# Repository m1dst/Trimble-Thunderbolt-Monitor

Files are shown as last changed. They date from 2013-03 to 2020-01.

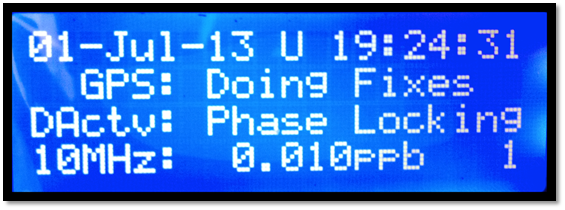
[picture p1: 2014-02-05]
Example-LCD.png

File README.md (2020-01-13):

**ATTENTION: We now support TinyCLR and as such the cheap GHI Fez which only costs $10**

If you are reading this for the first time and have not purchased a microcontroller yet, I suggest you use TinyCLR and the GHI Fez as the other boards are becomming more expensive and use the older NETMF.  Many suppliers have this board and an example supplier is [Mouser](https://www.mouser.co.uk/ProductDetail/GHI-Electronics/FEZT18-N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).  This will be the easiest way for you to run this project although the documentation I provide has yet to be updated so you will need to check out the ["getting started" guide](https://docs.ghielectronics.com/software/tinyclr/getting-started.html) on how to setup the environment for flashing the board.

**If you don't know how to use GitHub and just want to download the latest development code, visit [https://github.com/m1dst/Trimble-Thunderbolt-Monitor/archive/master.zip](https://github.com/m1dst/Trimble-Thunderbolt-Monitor/archive/master.zip).  You can always redownload the latest version with this link.  If you want an official releases, click the [releases link](https://github.com/m1dst/Trimble-Thunderbolt-Monitor/releases).**

Thunderbolt Monitor is a stand-alone microprocessor-controlled LCD specifically for the [Trimble Thunderbolt](http://www.trimble.com/timing/thunderbolt-e.aspx) disciplined clock, providing a comprehensive indication of the Thunderbolt's status, modes, and alarm conditions written in C# (NETMF).

Data packets appearing on Thunderbolt's serial port are in Trimble Standard Interface Protocol (TSIP), not NMEA sentences, so this display will not work with NMEA GPS units, such as Trimble's Jupiter or any other GPS.

Ideal for amateur radio applications, Thunderbolt Display shows Time Of Day (UTC) to assist with logging contacts, and also calculates Maidenhead Grid Locator Square from the current latitude and longitude.

The software runs on a [Netduino](https://www.wildernesslabs.co/) or [GHI FEZ Lemur](http://ghielectronics.com/) which is a .NET version of the popular Arduino platform.  It also requires a shield to make connecting it up to the microcontroller much cleaner.  I have designed the shield to be compatible with both Netduino and Arduino in case *someone wants to write code for the other platform.*

There are **four** projects in this repo.

* TrimbleMonitor (TinyCLR - Fez) – Basic monitor for the GHI FEZ (No NTP)
* TrimbleMonitor (Fez Lemur) – Basic monitor for the GHI FEZ Lemur (No NTP)
* TrimbleMonitor (Netduino) – Basic monitor for any Netduino 1, 2, 3 (No NTP)
* TrimbleMonitor (Netduno Plus) – Monitor with NTP support for a Netduino 2+ / 3 Ethernet / 3 WiFi

**The board must be running TinyCLR or [.NET Micro Framework 4.3](http://netmf.codeplex.com/releases/view/611040).  You should use [Visual Studio 2013](http://download.microsoft.com/download/2/5/5/255DCCB6-F364-4ED8-9758-EF0734CA86B8/wdexpress_full.exe) for NETMF projects and Visual Studio 2019 for TinyCLR.  More information can be found within the instructions document.**

Blog posts can be found at http://www.m1dst.co.uk/category/projects/trimble-thunderbolt-monitor/

Contains an NTP server implementation which allows you to sync your computer clock with the Trimble Thunderbolt.

You can now buy the shield as a PCB from [http://www.m1dst.co.uk/shop/](http://www.m1dst.co.uk/shop/)

The Netduino and GHI FEZ Lemur and GHI Fez are available from a few places but consistently seem to be in stock at Mouser.

**I do not have a version of the code for Arduino but I'm happy to include it in this repo if you wanted to write it.  The board I recommend now is the $10 GHI Fez running TinyCLR.  I have yet to update the instructions for flashing this but there are plenty of guides on the GHI website. **

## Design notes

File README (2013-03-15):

This is a hardware and software project to monitor and command a Trimble Thunderbolt which is a GPS disciplined 10MHz reference.

The software runs on a Netduino which is a .net version of the popular Arduino platform.  It also includes a shield to make connecting it up to the Netduino much cleaner.  I have designed the shield to be compatible with both Netduino are Arduino in case someone wants to port to the other platform.

Blog posts can be found at http://www.m1dst.co.uk/category/projects/trimble-thunderbolt-monitor/

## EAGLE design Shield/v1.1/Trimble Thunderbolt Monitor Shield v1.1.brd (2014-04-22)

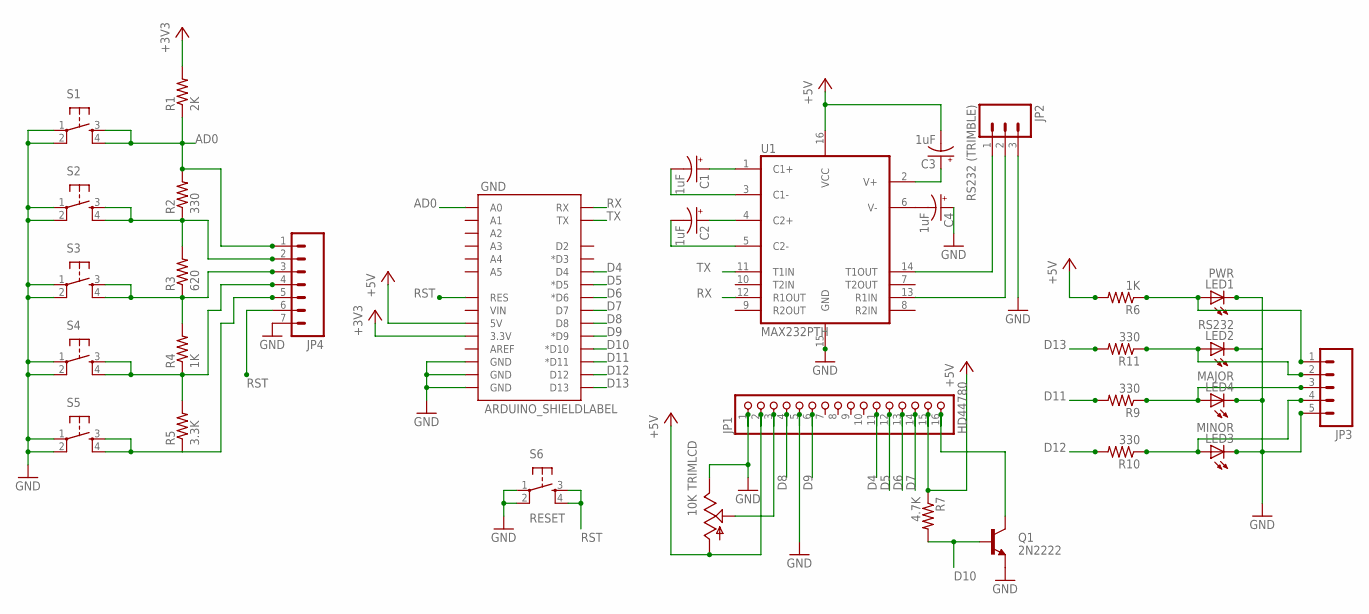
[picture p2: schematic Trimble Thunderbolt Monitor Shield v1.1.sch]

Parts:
C1, C2, C3, C4: 1uF; CPOL-RADIAL-10UF-25V
GND: ARDUINO_SHIELDLABEL; DUEMILANOVE_SHIELD
JP1: HD44780; 1X16
JP2: RS232 (TRIMBLE); MOLEX-1X3
JP3: M05PTH; 1X05
JP4: M07; 1X07
LED1: PWR; LED5MM
LED2: RS232; LED5MM
LED3: MINOR; LED5MM
LED4: MAJOR; LED5MM
Q1: 2N2222; TO-92-AMMO
R1: 2K; AXIAL-0.3
R2, R9, R10, R11: 330; AXIAL-0.3
R3: 620; AXIAL-0.3
R4, R6: 1K; AXIAL-0.3
R5: 3.3K; AXIAL-0.3
R7: 4.7K; AXIAL-0.3
S1, S2, S3, S4, S5: TAC_SWITCHPTH; TACTILE-PTH
S6: RESET; TACTILE-PTH
TRIMLCD: 10K; 3362U
U1: MAX232PTH; DIL16

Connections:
+3V3: GND.3.3V, R1.P$2 (2)
+5V: C3.2 (-), GND.5V, JP1.2, JP1.15, R6.P$2 (2), R7.P$1 (1), TRIMLCD.P$3 (A), U1.16 (VCC)
AD0: GND.A0, JP4.1, R1.P$1 (1), R2.P$2 (2), S1.3, S1.4
D4: GND.D4, JP1.11
D5: GND.D5 (*D5), JP1.12
D6: GND.D6 (*D6), JP1.13
D7: GND.D7, JP1.14
D8: GND.D8, JP1.4
D9: GND.D9 (*D9), JP1.6
D10: GND.D10 (*D10), Q1.2 (B), R7.P$2 (2)
D11: GND.D11 (*D11), R9.P$2 (2)
D12: GND.D12, R10.P$2 (2)
D13: GND.D13, R11.P$2 (2)
GND: C4.1 (+), GND.GND@0 (GND), GND.GND@1 (GND), GND.GND@2 (GND), JP1.1, JP1.5, JP2.3, JP3.5, JP4.7, LED1.K (C), LED2.K (C), LED3.K (C), LED4.K (C), Q1.1 (E), S1.1, S1.2, S2.1, S2.2, S3.1, S3.2, S4.1, S4.2, S5.1, S5.2, S6.1, S6.2, TRIMLCD.P$1 (E), U1.15 (GND)
LEDRS232: JP3.2, LED2.A, R11.P$1 (1)
unnamed: JP4.3, R3.P$1 (1), R4.P$2 (2), S3.3, S3.4
unnamed: JP3.3, LED4.A, R9.P$1 (1)
unnamed: JP4.4, R4.P$1 (1), R5.P$2 (2), S4.3, S4.4
unnamed: JP3.1, LED1.A, R6.P$1 (1)
unnamed: JP4.5, R5.P$1 (1), S5.3, S5.4
unnamed: JP2.1, U1.14 (T1OUT)
unnamed: JP1.16, Q1.3 (C)
unnamed: JP1.3, TRIMLCD.P$2 (S)
unnamed: JP2.2, U1.13 (R1IN)
unnamed: C1.2 (-), U1.3 (C1-)
unnamed: C1.1 (+), U1.1 (C1+)
unnamed: C2.1 (+), U1.4 (C2+)
unnamed: C2.2 (-), U1.5 (C2-)
unnamed: C4.2 (-), U1.6 (V-)
unnamed: C3.1 (+), U1.2 (V+)
unnamed: JP3.4, LED3.A, R10.P$1 (1)
unnamed: JP4.2, R2.P$1 (1), R3.P$2 (2), S2.3, S2.4
RST: GND.RES, JP4.6, S6.3, S6.4
RX: GND.RX, U1.12 (R1OUT)
TX: GND.TX, U1.11 (T1IN)

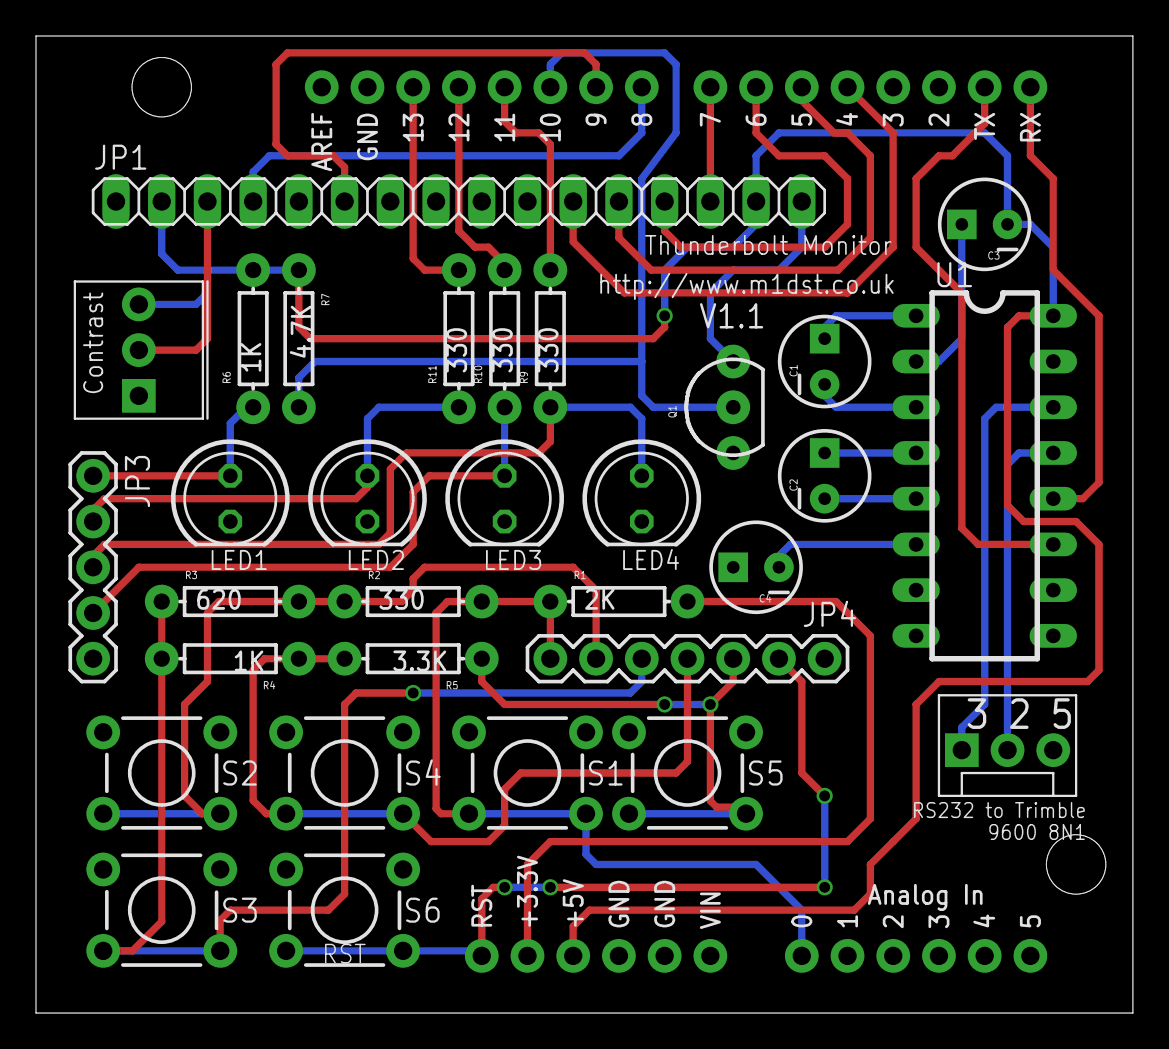
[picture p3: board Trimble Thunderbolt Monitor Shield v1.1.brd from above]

Board: 2 copper layers, 60.9 x 54.3 mm, 32 parts (0 on the bottom side), 35 nets.

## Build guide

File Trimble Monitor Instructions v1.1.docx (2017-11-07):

# Thunderbolt Monitor By M1DST

## Overview

Thunderbolt Monitor is a stand-alone microprocessor-controlled LCD specifically for Trimble’s Thunderbolt disciplined clock, providing a comprehensive indication of the Thunderbolt's status, modes, and alarm conditions.

Data packets appearing on Thunderbolt's serial port is HEX data in Trimble Standard Interface Protocol (TSIP), not NMEA sentences, so this display will not work with NMEA GPS units, such as Trimble's Jupiter or any other GPS.

Ideal for amateur radio applications, Thunderbolt Display shows Time Of Day (UTC) to assist with logging contacts, and also calculates Maidenhead Grid Locator Square from the current latitude and longitude.

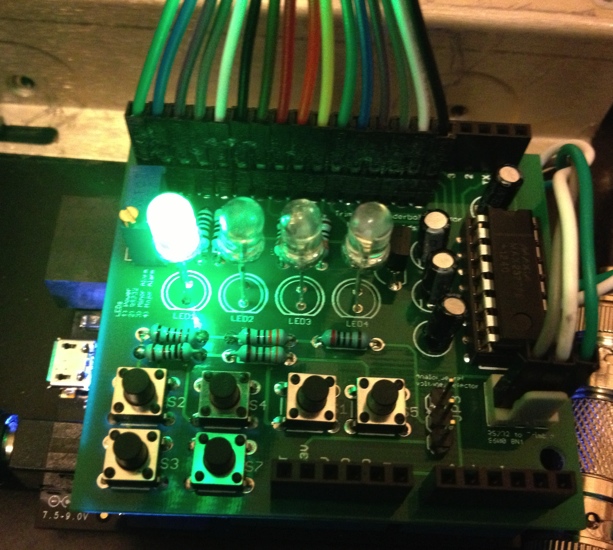
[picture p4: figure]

## Features

- 4 line x 20 character backlit LCD
- 5 information pages
- Alarm outputs (LEDs)
- NTP Server
- 3 Programmable buttons to send commands
- Open source hardware and software
- Shield for use with Netduino or Arduino
- Required 7.5 – 12V input (or USB powered)

## Display Pages

- Page 1: Status
- Page 2: Mode/Survey
- Page 3: Location
- Page 4: Alarms
- Page 5: Network configuration
- Splash: Shown during boot time
- Error: Shown when no data is being received.

## Sample Screen

This is an example of a screen from my Thunderbolt Monitor.

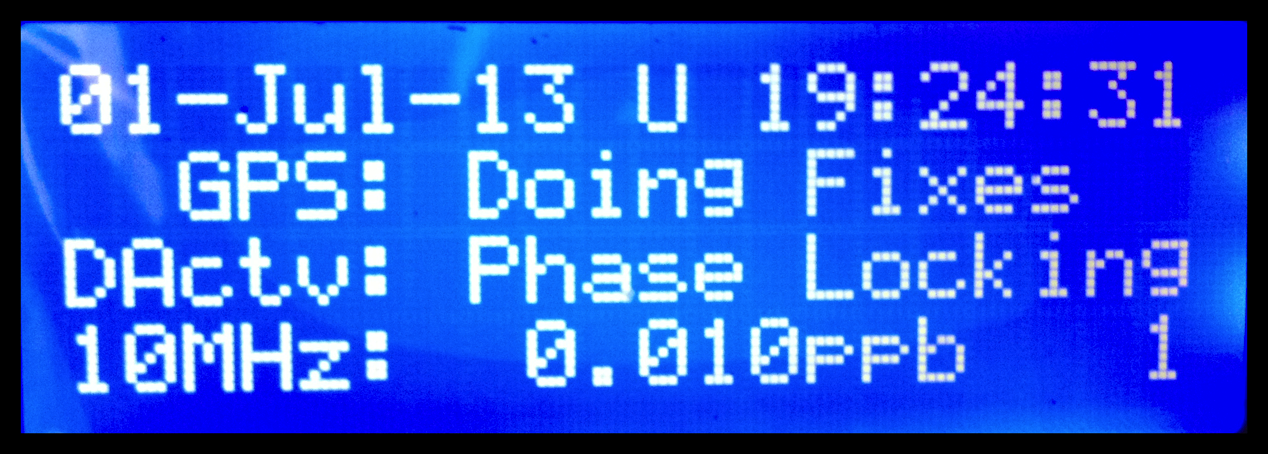
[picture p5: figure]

## Parts List

Type | Part | Value | Comment | Packed | Installed
PCB | PCB | -
Capacitor | C1, C2, C3, C4 | 1uF
LED | LED1 | Green | Power
LED | LED2 | Blue | RS232
LED | LED3 | Orange | Minor
LED | LED4 | Red | Major
Transistor | Q1 | 2N2222 | NPN
Resistor | R1 | 2K
Resistor | R2, R9, R10, R11 | 330R
Resistor | R3 | 620R
Resistor | R4, R6 | 1K
Resistor | R5 | 3.3K
Resistor | R7 | 4.7K
Switch | S1, S2, S3, S4, S5, S6 | -
Header | JP1 | 16 pins | LCD
Header | JP2 | 3 pins | RS232
Header | JP3 | 5 Pins | External LEDs
Header | JP4 | 7 Pins | External buttons
Header | - | 16 Pins | Solder to LCD
IC | U1 | MAX232CPE | Use provided socket
Cable | - | 16 core ribbon cable | Use with LCD
LCD | LCD | 4x20 LCD
Header | - | Shield Headers | 4 to install.
Pot | - | 10K Pot | LCD Contrast

Notes:

You don’t have to install JP3 or JP4 unless you are going to use external LEDs and/or buttons. If you are installing external LEDs then you shouldn’t install the on-board ones. You may install on-board and external buttons if you wish.

I recommend you tick off the components as you install them.

## RS232 Plug

The Thunderbolt uses a DB9 to connect to the monitor via JP2. You will need to connect to pins 2, 3 and 5 of the DB9. The wiring is clearly labelled on the PCB.

Pin 2 – TX data from the Thunderbolt

Pin 3 – RX data to the Thunderbolt

Pin 5 – GND

The Thunderbolt Monitor can be wired in parallel with another DB9 that connects to a PC/laptop.

The monitor only accepts data at the Thunderbolt's default serial port parameters. (9600 baud, 8 data bits, no parity, 1 stop bit)

## Schematic

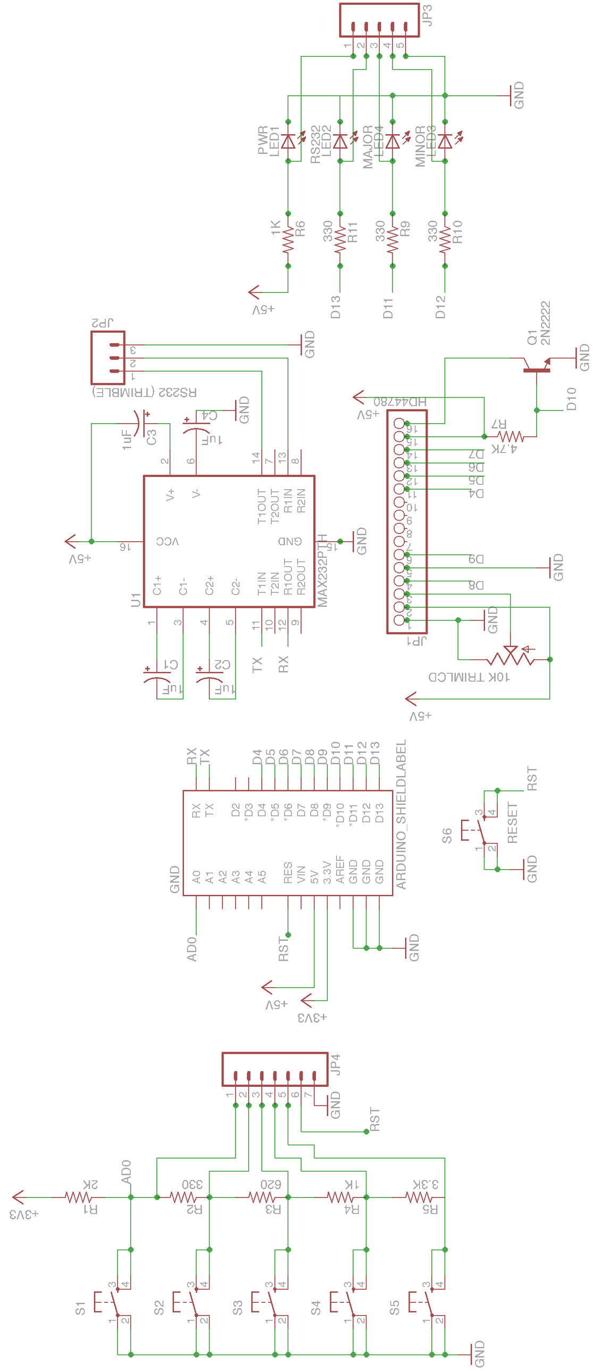
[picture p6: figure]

## Buttons

There are 6 buttons in use for the Thunderbolt Monitor. The buttons operate as follows:

UP (S2) | Navigates forwards through the Monitor’s screens
DOWN (S3) | Navigates backwards through the Monitor’s screens
BTN1 (S4) | Switches the receiver into Full 3D Position mode
BTN2 (S1) | Switches the receiver into Over Determined Clock mode.
BTN3 (S5) | Starts a Site Survey.
RESET (S7) | Forces the Netduino to reboot. You may need this is your unit locks up.

Over Determined Clock mode is the optimum mode for Time-only fixes and is important for disciplining the internal 10MHz oscillator to the best accuracy. It is does not report position whilst in this mode.

You would need to switch to Full 3D Position mode if you wish the Latitude and Longitude to update if you were to be mobile.

## Deploying to the NETMF board.

This project has was originally designed for the Netduino Plus 2. The Netduino is an open source electronics platform using the .NET Micro Framework. Since then I have created a version without the NTP functionality for the original Netduino, Netduino 2, and GHI FEZ Lemur. If you have a Netduino 3 then you should also be fine.

The project requires your board to be at version 4.3 of the firmware.

To deploy or modify the Monitor you’ll need some free tools.

WARNING: You should NOT use Visual Studio 2015. It will not work. Use Visual Studio 2013 instead. You can get the free version from http://download.microsoft.com/download/2/5/5/255DCCB6-F364-4ED8-9758-EF0734CA86B8/wdexpress_full.exe

If you are installing on a Netduino, follow the instructions at http://developer.wildernesslabs.co/Netduino/About/Downloads to ensure you have all the prerequisites.

If you are installing on a GHI FEZLemur, follow the instructions at https://www.ghielectronics.com/support/netmf to ensure you have all the prerequisites.

Open TrimbleMonitor.sln using Visual Studio.

There are currently three projects in the solution.

- TrimbleMonitor (Fez Lemur) – Basic monitor for the GHI FEZ Lemur (No NTP)
- TrimbleMonitor (Netduino) – Basic monitor for any Netduino 1,2,3 (No NTP)
- TrimbleMonitor (Netduno Plus) – Monitor with NTP support for a Netduino 2+/3 Ethernet/Wifi

You should right click the project which fits your hardware and click “Set as StartUp project” within the solution explorer.

By default, Visual Studio runs projects in an emulator. This allows software developers to create and test programming logic for a new hardware product before the actual hardware is built. We won’t use the emulator for our purposes, so we’ll let Visual Studio know that we have physical hardware it should use instead.

Click on the Project menu and select your project’s properties (generally, the last item in the Projects menu). When the project properties appear, click on the “.NET Micro Framework” category on the left side.

Now we will change our deployment target from the Emulator to the Netduino/Lemur. Change the Transport from “Emulator” to “USB” and then make sure that the Device selection box shows your device. If it doesn’t, unplug and re-attach it.

Now, we’ll run the project. When we run the project, the code is deployed to the board and then automatically started.

To run your project, press the “Start Debugging” button in the toolbar at the top of the screen. It looks like the Play button on a music player. You can also press F5 instead.

Visual Studio will now deploy the Trimble Monitor to the hardware. In a few seconds, you’ll see the LCD fire into life and the blue LED blinking on and off every time it receives data from the Thunderbolt.

When you ran the program, it was written to the microcontroller so all you have to do to run the program again is plug it in via a micro USB cable or with a power adapter (using the power barrel jack).

You should see the splash screen appear, the LEDs flash in a pattern and the then the main program start to show you the status of your Thunderbolt.

Congratulations, you now have a working Thunderbolt Monitor.

## Photos

I am compiling photos from fellow builders which I plan to display on my website. If you would like to see your project shown on my site then please email me your photos and I will display them at http://www.m1dst.co.uk. My email address is james@m1dst.co.uk.

I hope you get as much enjoyment from this project as I did putting it together.

James, M1DST

## Networking

Many network settings, such as which WiFi network to connect to, or whether or not to use DHCP (or a static IP), are configured at deploy time via MFDeploy on Windows (Mac network configuration support is in progress).

MFDeploy is included in the .NET MicroFramework installation. To configure network settings on Netduino, launch MFDeploy from the start menu and then access the settings via the Target > Configuration > Network menu:

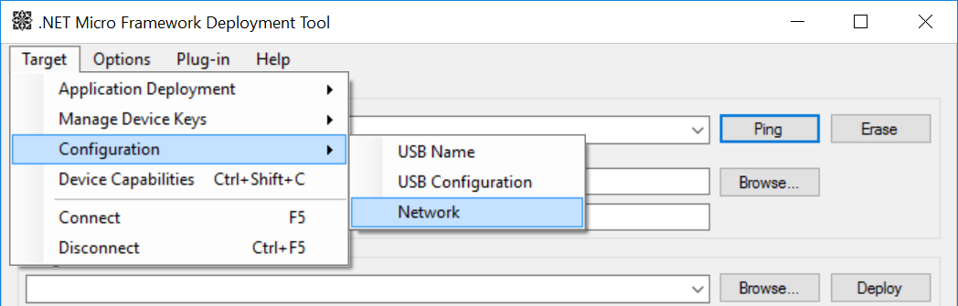
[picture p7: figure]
Menu navigation in MFDeploy to launch the Network Configuration popup

From there, Network settings are configured in the popup. For example, the following settings will configure a WiFi enabled Netduino 3 to connect to the open wireless network “Cabin in the Woods” using 802.11 b, g, or n radio and use DHCP to obtain an IP Address

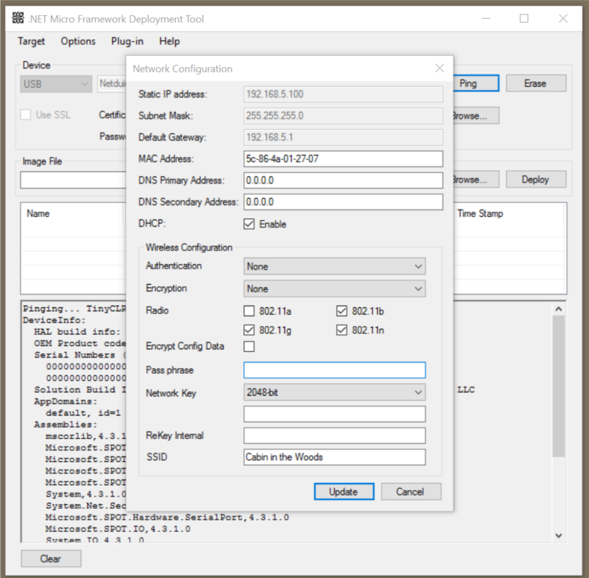
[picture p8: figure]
The Network Configuration popup in MFDeploy

Note that if you get the error unable to erase configuration sector memory, when trying to save, you may have to close the network settings dialog and run Plug-in > Reboot Stop from the menu first.

[Type text][Type text][Type text]

Thunderbolt Monitorhttp://www.m1dst.co.ukTwitter: @m1dst

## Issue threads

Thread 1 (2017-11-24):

Add support for LCD backlight brightness

m1dst, 2017-11-24:
There was provision made on the PCB to control the brightness of the LCD.  It should be possible to set a value in the code prior to deployment.

The default should be 100%.

I don't see any sense in creating any kind of UI to manage this as it is likely only set once and left.  It would be just as easy for someone to change the value and redeploy.

g4fre, 2018-02-07:
Having this feature would be good. setting its value before deployment would work as it will not need to be changed often. My LCD  illuminates the whole shack

m1dst, 2018-02-18:
This is experimental.  If you find any issues with hanging we should roll this feature back.  It took several hours, around 15 PC hangs and many deployments to get to this state.

Annoyingly it ended up being 6 lines of code.

The biggest issue was instantiating the PWM too early.  I almost gave up as the Netduino would crash for no apparent reason after about 11 seconds.  Eventually with trial an error I found that if I enabled PWM later in the startup, the Netduino didn't crash and stayed stable.

To modify the brightness, open Program.cs and find the following line towards the top of the file...

```
        const byte LcdBrighness = 100;
```

The default is 100.

Good luck.  Please report any issues.

Closed 2018-02-18.

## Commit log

2013-03-15 Initial check in
    This is the first version of the Trimble Thunderbolt Shield. I have
    done my best to check it but as yet it hasn't been fabricated so please
    check it yourself if you are going to create one.
    [Trimble Thunderbolt Monitor Shield v1.brd, Trimble Thunderbolt Monitor Shield v1.sch]
2013-03-18 Changed the pot used for LCD contrast to a 3362U package.
    [Trimble Thunderbolt Monitor Shield v1.brd, Trimble Thunderbolt Monitor Shield v1.sch]
2013-03-18 Backlight and track routing changes
    Changes to the layout of some of the tracks to make them look neater.
    Also changed the way the backlight interacts with the Netduino. It is
    now possible to control the brightness of the LCD via a pin on the
    Netduino.
    Also changed some of the LED output pins
    [Trimble Thunderbolt Monitor Shield v1.brd, Trimble Thunderbolt Monitor Shield v1.sch]
2013-03-18 A few silkscreen changes
    [Trimble Thunderbolt Monitor Shield v1.brd]
2013-03-18 Updated some more silkscreen items, a few traces and added gerber files.
    [Trimble Thunderbolt Monitor Shield v1.GBL, Trimble Thunderbolt Monitor Shield v1.GBO, Trimble Thunderbolt Monitor Shield v1.GBP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]
2013-11-25 Enhanced the manual
    Added information to the manual to explain the use of the buttons.
2014-01-19 Created v1.1
    Added a new version of the shield. I’ve added headers for external
    buttons and LEDs rather than soldering directly to the board. The
    manual has been updated with these changes.
    Various components have been renamed to make the numbering more
    consistent.
    [Trimble Thunderbolt Monitor Shield v1.0.brd, Trimble Thunderbolt Monitor Shield v1.0.sch, Trimble Thunderbolt Monitor Shield v1.1.brd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]
2014-02-04 Fixed some silkscreen issues
    [Trimble Thunderbolt Monitor Shield v1.0.brd, Trimble Thunderbolt Monitor Shield v1.0.sch, Trimble Thunderbolt Monitor Shield v1.1.brd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]
2014-02-04 Removed old berbers
    [Trimble Thunderbolt Monitor Shield v1.GBL, Trimble Thunderbolt Monitor Shield v1.GBO, Trimble Thunderbolt Monitor Shield v1.GBP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]
2014-02-04 Fixed some ERC issues
    [Trimble Thunderbolt Monitor Shield v1.0.brd, Trimble Thunderbolt Monitor Shield v1.0.sch]
2014-02-04 Updated the manuals
    Updated the schematic, and button instructions to make it clearer which
    button is which. There is still work required to label the new headers
    on v1.1
2014-04-22 Subtle cleanup of the v1.1 board and gerber files
    [Trimble Thunderbolt Monitor Shield v1.1.GBL, Trimble Thunderbolt Monitor Shield v1.1.GBO, Trimble Thunderbolt Monitor Shield v1.1.GBP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]
2014-04-22 Changed board font to vector
    [Trimble Thunderbolt Monitor Shield v1.1.brd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]
2017-08-10 Added support for FEZ Lemur
    Changed the namespaces to make them simpler.
    Add .vs to the gitignore file.
    Add shared AssemblyInfo file.
    Create project files for each type of board with shared files.
    Updated the instructions to reflect new projects.
2019-09-04 Added a watchdog to the TinyCLR version to allow recovery.
    The watchdog timeout is currently 30s and is being reset at the start of every loop.

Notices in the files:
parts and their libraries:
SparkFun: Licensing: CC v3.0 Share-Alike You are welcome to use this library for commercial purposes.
